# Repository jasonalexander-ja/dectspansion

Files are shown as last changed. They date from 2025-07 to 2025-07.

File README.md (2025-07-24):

# DECTspansion 

A DECT module for your EMFCamp Tildagon badge. 

Requires a headphone input. 

Based on [sc14cvmdect-devboard](https://github.com/funkeleinhorn/sc14cvmdect-devboard) by [funkeleinhorn](https://github.com/funkeleinhorn) and [EMFCamp](https://www.emfcamp.org/) [hexpansion](https://github.com/emfcamp/badge-2024-hardware/tree/main/hexpansion). 

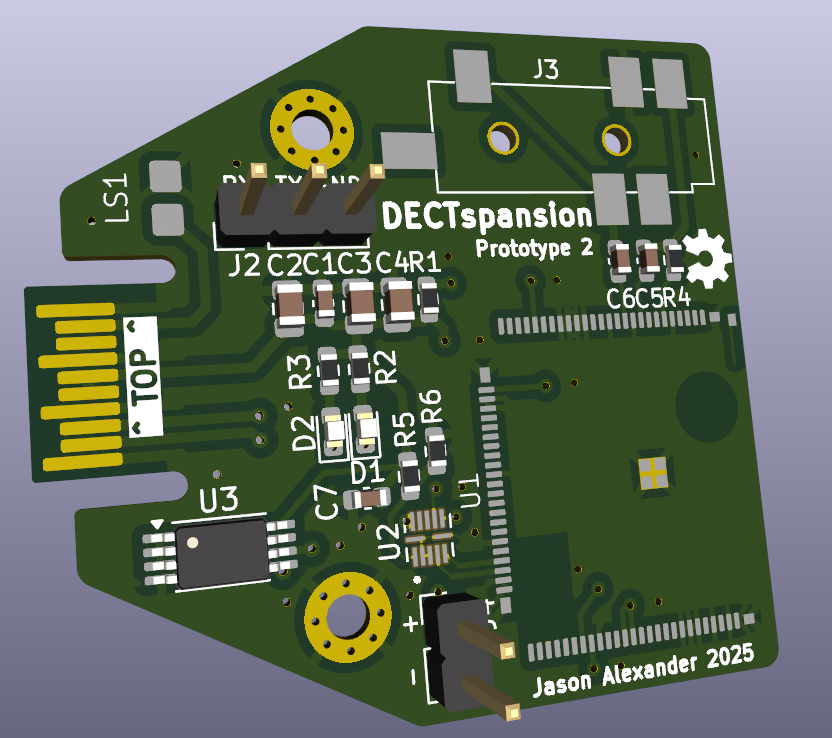
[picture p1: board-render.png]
Rendered image of the front of the PCB.


Currently in early prototype stage. 

## Components 

| Component | Value | Footprint |
|---|---|---|
| C1 | 47pF | 0603 |
| C2 | 2.2uF | 0805 |
| C3 | 10uF | 0805 |
| C4 | 2.2uF | 0805 |
| C5 | 100nF | 0603 |
| C6 | 1nF | 0603 |
| C7 | 47pF | 0603 |
| D1 | OSK40603C1E | 0603 |
| D2 | ORH-B36G | 0603 |
| J2 | 1x3 Pin header | 2.54mm |
| J3 | SJ-4351X | SMT audio jack |
| J4 | 1x2 Pin header | 2.54mm |
| R1 | 1K | 0603 |
| R2 | 470R | 0603 |
| R3 | 470R | 0603 |
| R4 | 1K | 0603 |
| R5 | 1K | 0603 |
| R6 | 1K | 0603 |
| U1 | SC14VCMDECT | |
| U2 | 74AVC4T3144 | XQFN12 |
| U3 | ZD24C64A | TSSOP-8 |
| LS1 | CMT-322-65 | |

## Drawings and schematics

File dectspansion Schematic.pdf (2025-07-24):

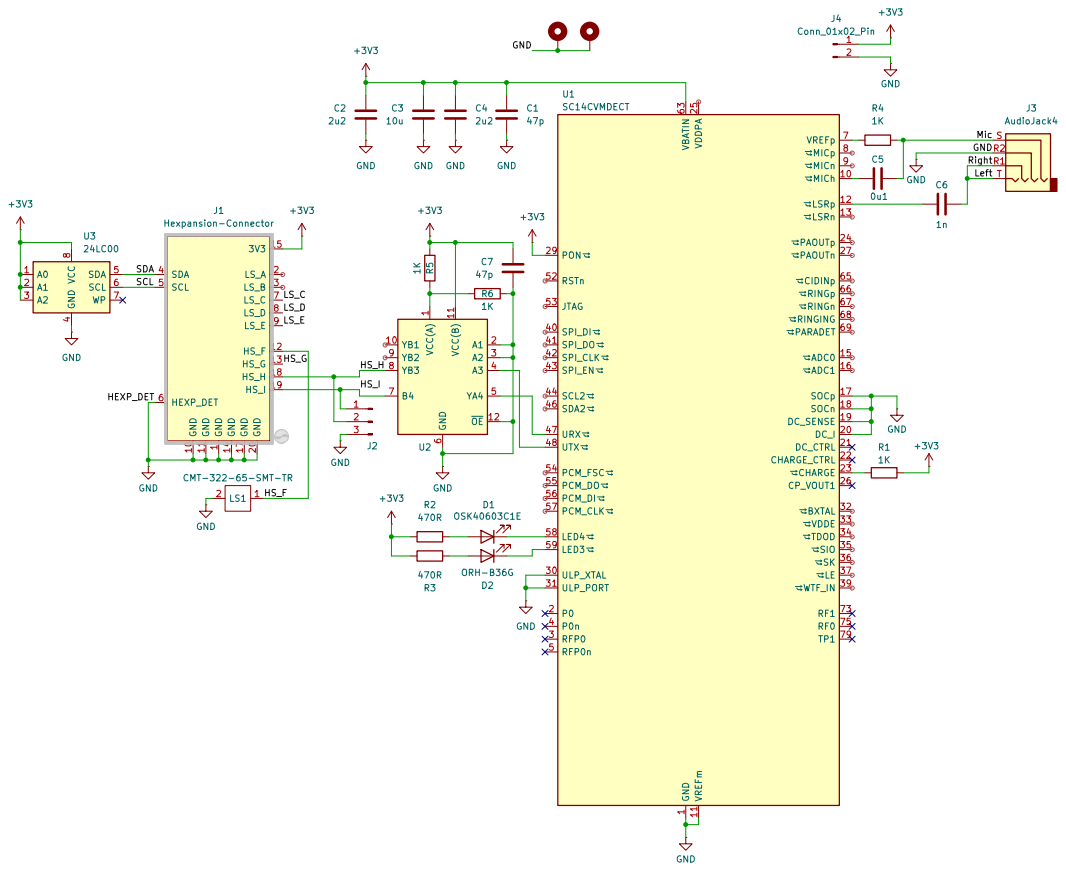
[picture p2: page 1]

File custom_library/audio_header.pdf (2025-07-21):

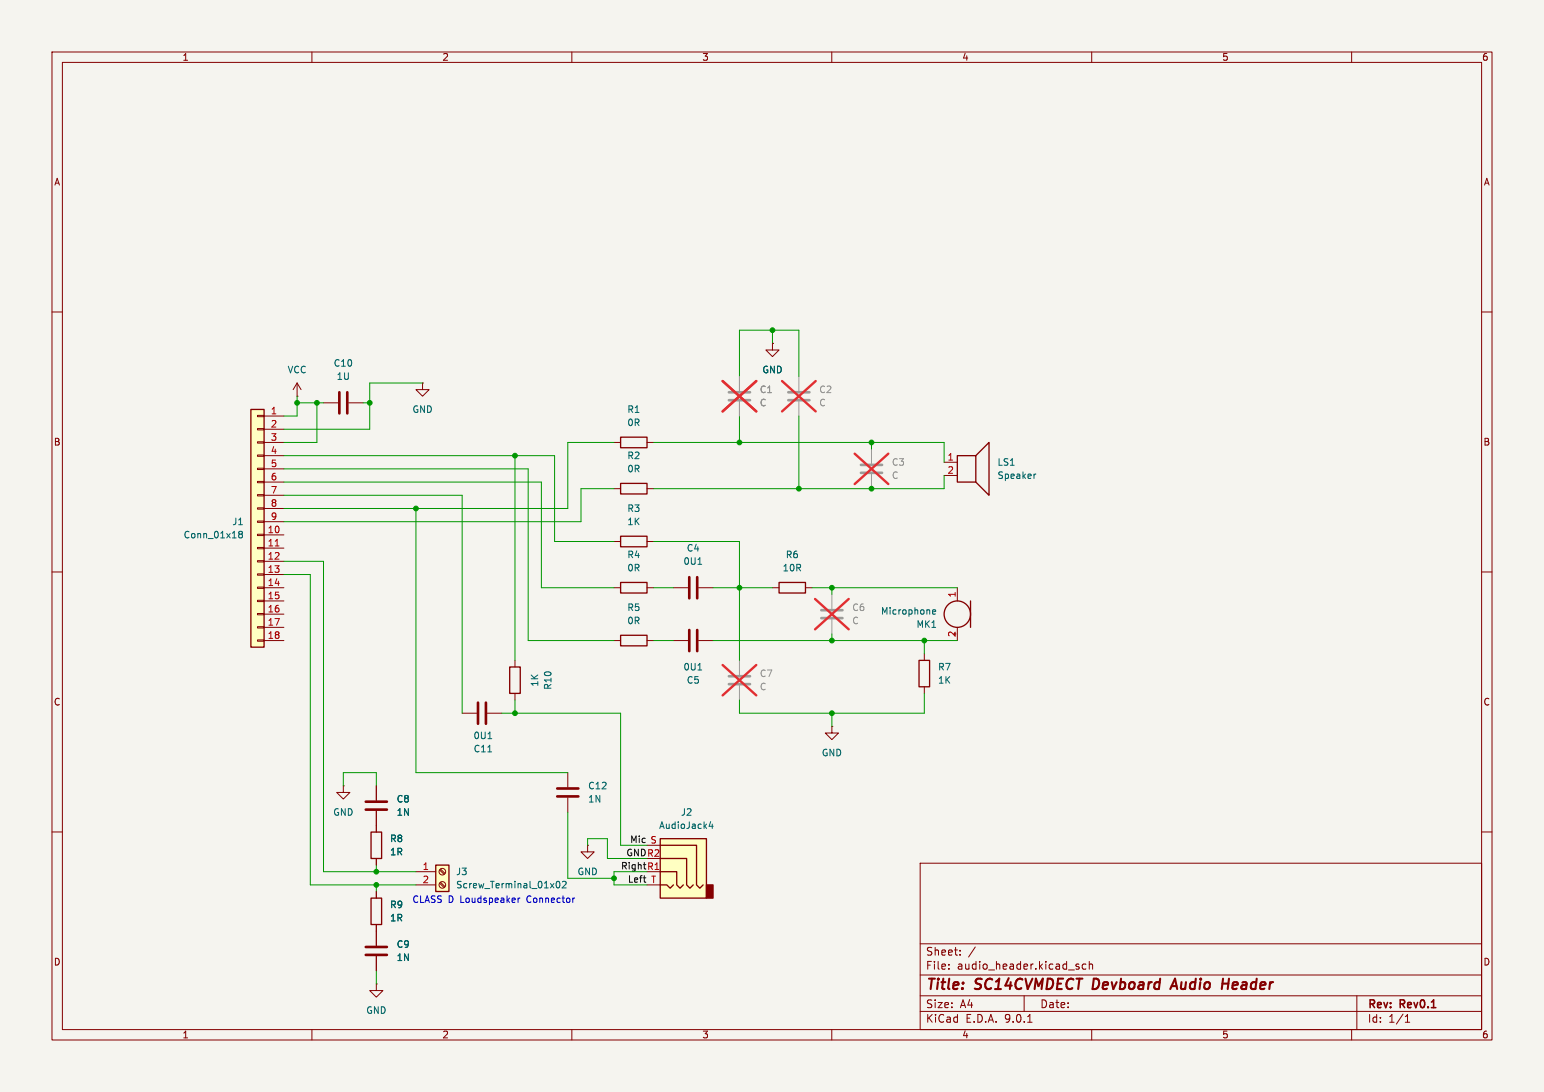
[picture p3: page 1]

10 11 12

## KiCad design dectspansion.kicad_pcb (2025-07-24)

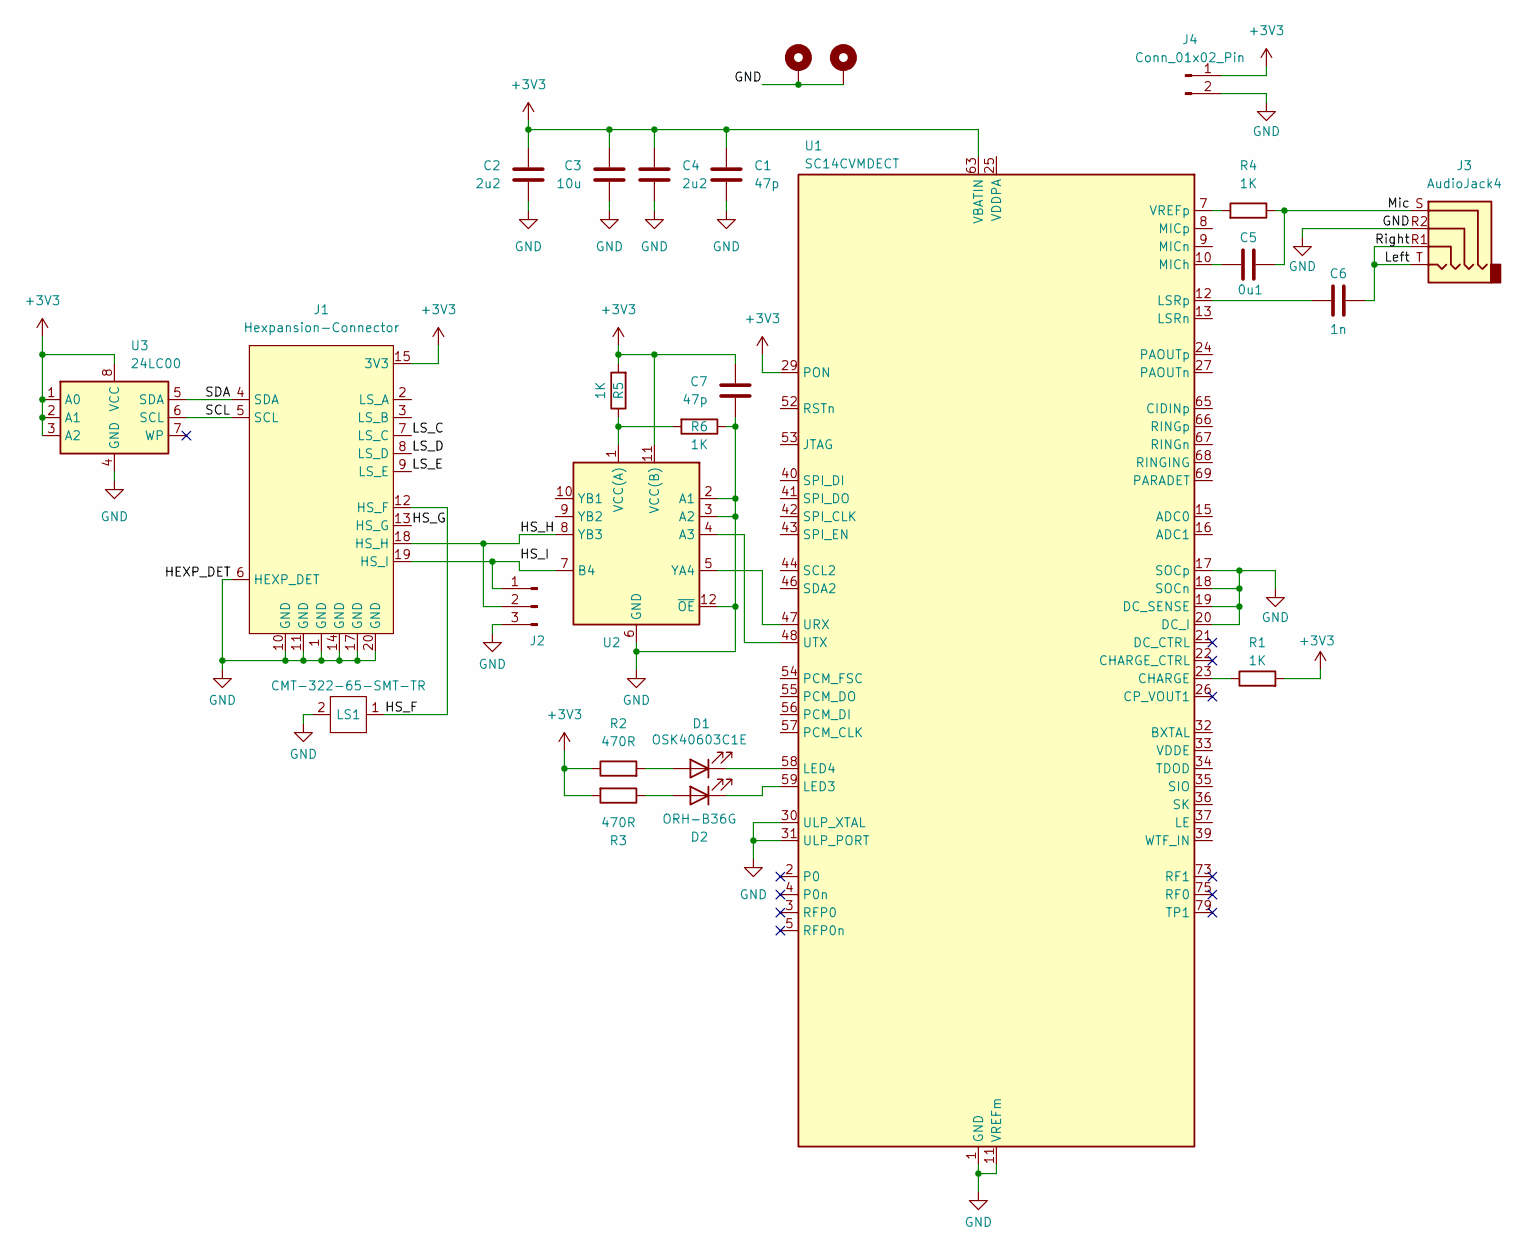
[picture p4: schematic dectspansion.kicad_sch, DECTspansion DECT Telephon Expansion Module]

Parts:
C1, C7: 47p; C_0603_1608Metric
C2, C4: 2u2; C_0805_2012Metric
C3: 10u; C_0805_2012Metric
C5: 0u1; C_0603_1608Metric
C6: 1n; C_0603_1608Metric
D1: OSK40603C1E; LED_0603_1608Metric
D2: ORH-B36G; LED_0603_1608Metric
H1, H2: MountingHole_Pad; MountingHole_2.2mm_M2_Pad_Via
J1: Hexpansion-Connector; hexpansion-edge-connector
J2: Conn_01x03_Pin; PinHeader_1x03_P2.54mm_Vertical
J3: AudioJack4; Jack_3.5mm_CUI_SJ-4351X-SMT_Horizontal
J4: Conn_01x02_Pin; PinHeader_1x02_P2.54mm_Vertical
LS1: CMT-322-65-SMT-TR
R1, R4, R5, R6: 1K; R_0603_1608Metric
R2, R3: 470R; R_0603_1608Metric
U1: SC14CVMDECT
U2: 74AVC4T3144
U3: 24LC00; TSSOP-8_4.4x3mm_P0.65mm

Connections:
+3V3: C1.1, C2.1, C3.1, C4.1, C7.1, J1.15 (3V3), J1.16 (3V3), J4.1, R1.2, R2.1, R3.2, R5.2, U1.29 (PON), U1.63 (VBATIN), U1.64 (VBATIN), U2.11 (VCC(B)), U3.1 (A0), U3.2 (A1), U3.3 (A2), U3.8 (VCC)
/HS_F: J1.12 (HS_F), LS1.1
/HS_G: J1.13 (HS_G)
/HS_H: J1.18 (HS_H), J2.2, U2.8 (YB3)
/HS_I: J1.19 (HS_I), J2.1, U2.7 (B4)
/LS_C: J1.7 (LS_C)
/LS_D: J1.8 (LS_D)
/LS_E: J1.9 (LS_E)
/Left: C6.1, J3.R1, J3.T
/Mic: C5.2, J3.S, R4.1
/SCL: J1.5 (SCL), U3.6 (SCL)
/SDA: J1.4 (SDA), U3.5 (SDA)
GND: C1.2, C2.2, C3.2, C4.2, C7.2, H1.1, H2.1, J1.1 (GND), J1.6 (HEXP_DET), J1.10 (GND), J1.11 (GND), J1.14 (GND), J1.17 (GND), J1.20 (GND), J2.3, J3.R2, J4.2, LS1.2, R6.1, U1.1 (GND), U1.6 (GND), U1.11 (VREFm), U1.14 (GND), U1.17 (SOCp), U1.18 (SOCn), U1.19 (DC_SENSE), U1.20 (DC_I), U1.28 (GND), U1.30 (ULP_XTAL), U1.31 (ULP_PORT), U1.38 (GND), U1.45 (GND), U1.49 (GND), U1.50 (GND), U1.51 (GND), U1.60 (GND), U1.70 (GND), U1.71 (GND), U1.72 (GND), U1.74 (GND), U1.76 (GND), U1.77 (GND), U1.78 (GND), U1.80 (GND), U2.2 (A1), U2.3 (A2), U2.6 (GND), U2.12 (~OE), U3.4 (GND)
unnamed: D1.2 (A), R2.2
unnamed: D1.1 (K), U1.58 (LED4)
unnamed: D2.2 (A), R3.1
unnamed: D2.1 (K), U1.59 (LED3)
unnamed: R1.1, U1.23 (CHARGE)
unnamed: C6.2, U1.12 (LSRp)
unnamed: C5.1, U1.10 (MICh)
unnamed: U1.47 (URX), U2.5 (YA4)
unnamed: U1.48 (UTX), U2.4 (A3)
unnamed: R4.2, U1.7 (VREFp)
unnamed: R5.1, R6.2, U2.1 (VCC(A))

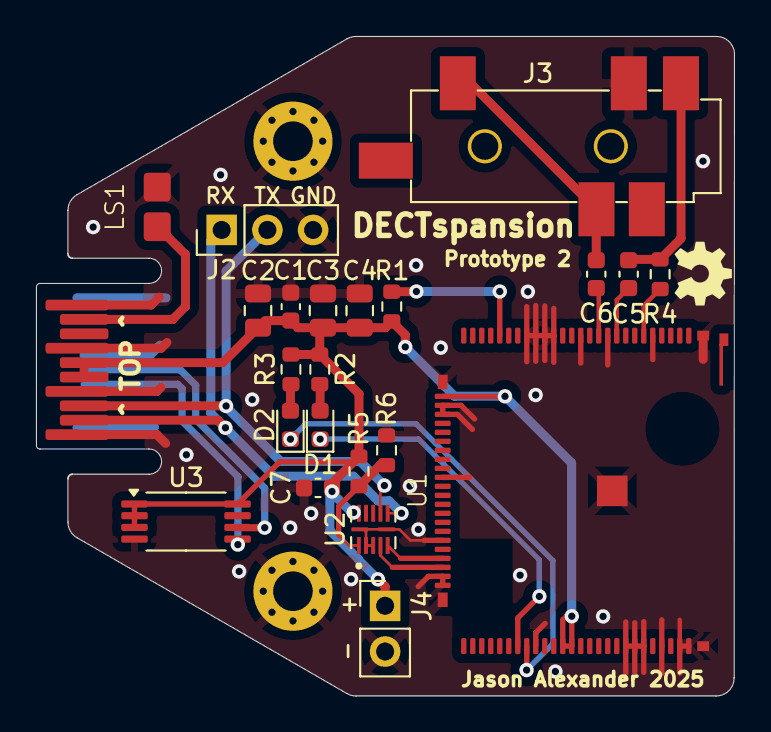
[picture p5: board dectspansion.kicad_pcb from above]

Board: 4 copper layers, 38.8 x 36.6 mm, 25 parts (0 on the bottom side), 20 nets.

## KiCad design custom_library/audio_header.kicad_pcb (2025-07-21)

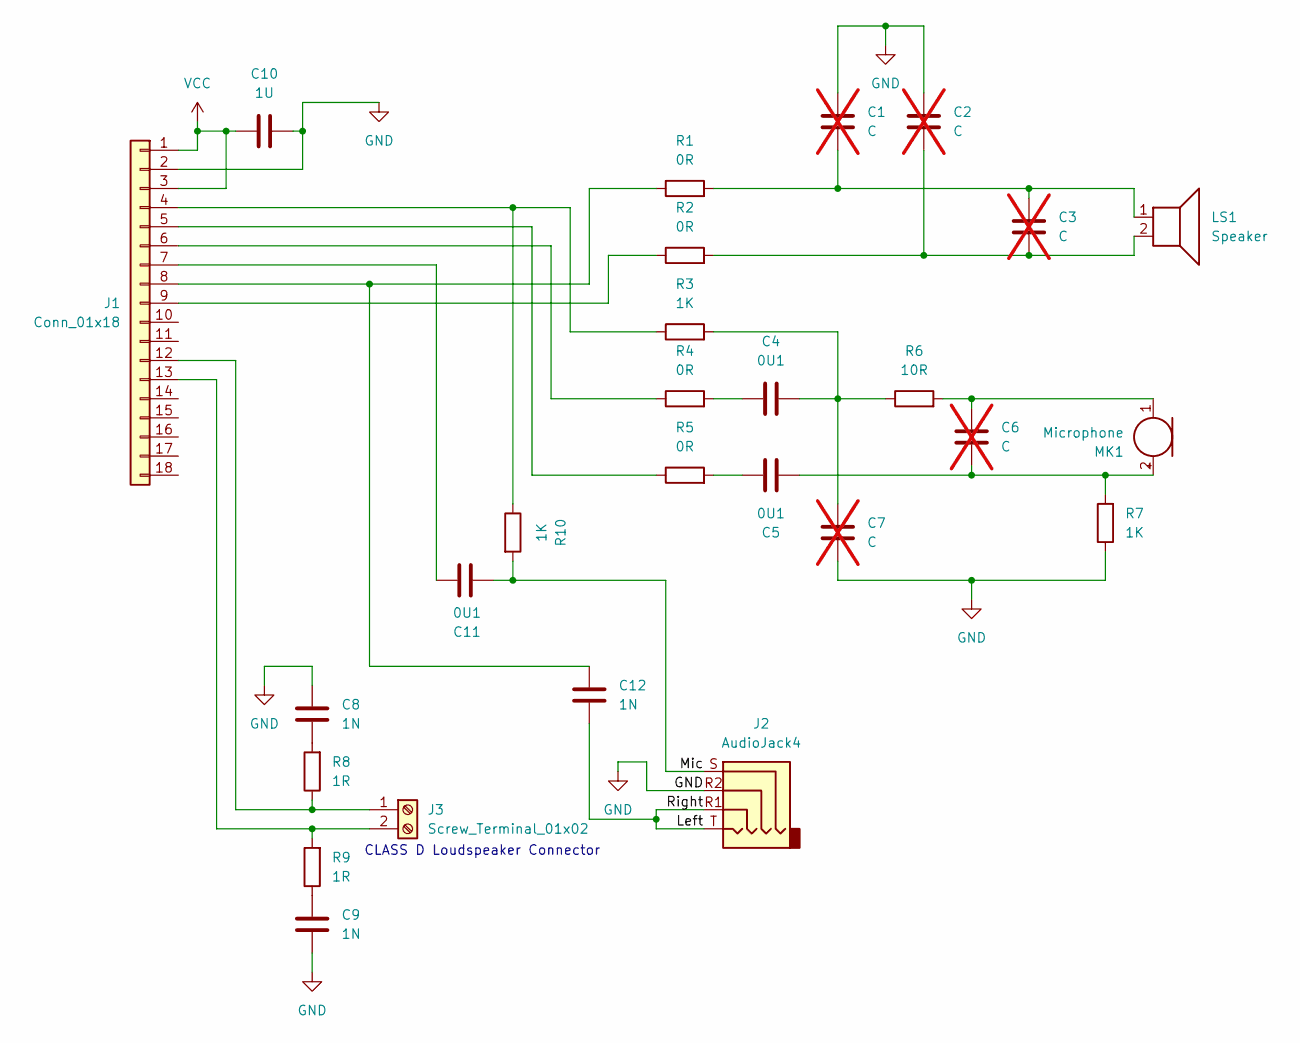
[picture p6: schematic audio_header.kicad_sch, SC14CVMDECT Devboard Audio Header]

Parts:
C1, C2, C3, C6, C7: C; C_0603_1608Metric; not fitted
C4, C5, C11: 0U1; C_0603_1608Metric
C8, C9, C12: 1N; C_0603_1608Metric
C10: 1U; C_0603_1608Metric
J1: Conn_01x18; PinSocket_1x18_P2.54mm_Vertical
J2: AudioJack4; Jack_3.5mm_CUI_SJ-4351X-SMT_Horizontal
J3: Screw_Terminal_01x02; TerminalBlock_MaiXu_MX126-5.0-02P_1x02_P5.00mm
LS1: Speaker; Speaker_CUI_CMR-15062S-67
MK1: Microphone; CUI_CMC-4013-SMT
R1, R2, R4, R5: 0R; R_0603_1608Metric
R3, R7, R10: 1K; R_0603_1608Metric
R6: 10R; R_0603_1608Metric
R8, R9: 1R; R_0603_1608Metric

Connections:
/Left: C12.1, J2.R1, J2.T
/Mic: C11.2, J2.S, R10.2
GND: C1.1, C2.1, C7.2, C8.2, C9.1, C10.2, J1.2, J2.R2, R7.1
unnamed: C1.2, C3.1, LS1.1, R1.2
unnamed: C2.2, C3.2, LS1.2, R2.2
unnamed: C4.1, R4.2
unnamed: C4.2, C7.1, R3.2, R6.1
unnamed: C5.1, R5.2
unnamed: C8.1, R8.2
unnamed: C9.2, R9.1
unnamed: J1.4, R3.1, R10.1
unnamed: J1.5, R5.1
unnamed: J1.6, R4.1
unnamed: C11.1, J1.7
unnamed: C12.2, J1.8, R1.1
unnamed: J1.9, R2.1
unnamed: J1.12, J3.1, R8.1
unnamed: J1.13, J3.2, R9.2
unnamed: C5.2, C6.2, MK1.2 (+), R7.2
unnamed: C6.1, MK1.1 (-), R6.2
VCC: C10.1, J1.1, J1.3

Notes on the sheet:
CLASS D Loudspeaker Connector

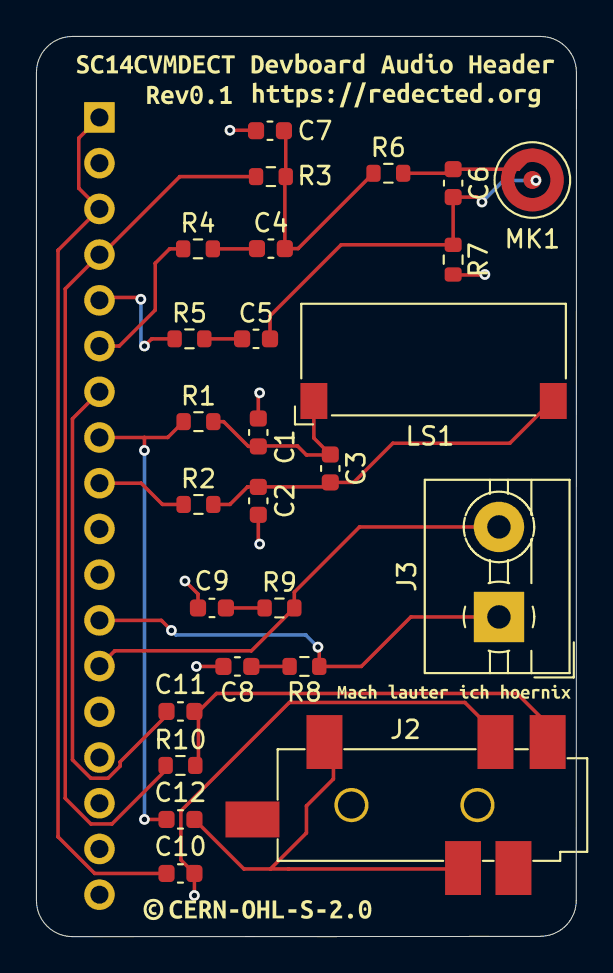
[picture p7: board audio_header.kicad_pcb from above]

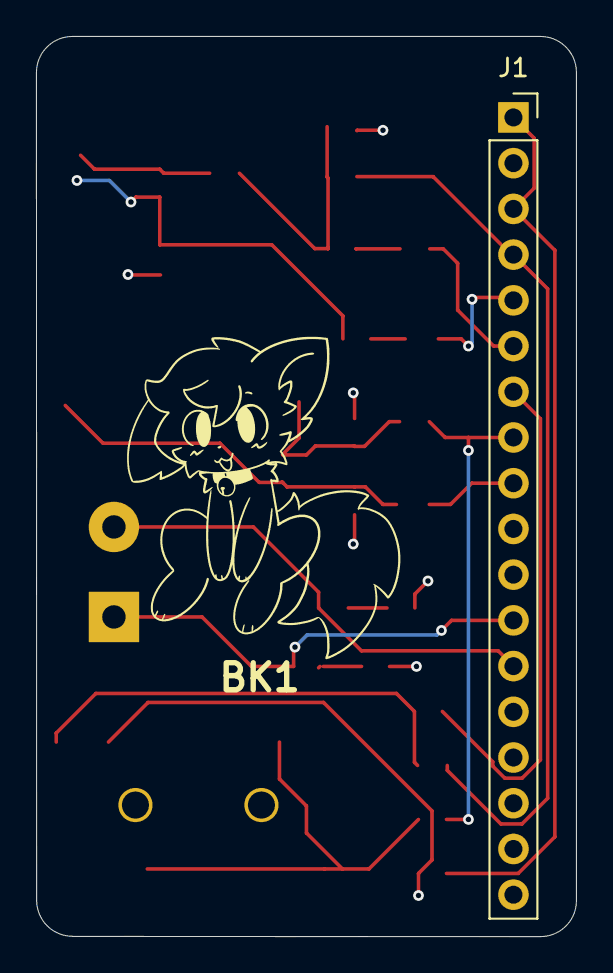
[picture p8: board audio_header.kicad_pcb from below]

Board: 4 copper layers, 30.0 x 50.0 mm, 34 parts (2 on the bottom side), 21 nets.

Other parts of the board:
BK1: LOGO
kibuzzard-67A72E30: G***; kibuzzard-67A72E30
kibuzzard-67A72F6B: G***; kibuzzard-67A72F6B
kibuzzard-67A72F64: G***; kibuzzard-67A72F64
kibuzzard-67A72F83: G***; kibuzzard-67A72F83
kibuzzard-67A7302E: G***; kibuzzard-67A7302E
kibuzzard-67ACE384: G***; kibuzzard-67ACE384

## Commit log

2025-07-21 Created PCB layout
    [dectspansion.kicad_pcb, dectspansion.kicad_sch]
2025-07-21 Adjustments to PCB layout
    [dectspansion.kicad_pcb]
2025-07-21 Added gerbers
    [dectspansion-B_Cu.gbl, dectspansion-B_Mask.gbs, dectspansion-B_Paste.gbp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]
2025-07-22 Adjustments to schmatic, board layout, and added part list to readme
    [dectspansion-B_Cu.gbl, dectspansion-B_Mask.gbs, dectspansion-B_Paste.gbp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]
2025-07-22 Added gerbers to zip
2025-07-22 Added uart level shifting
    [dectspansion-B_Cu.gbl, dectspansion-B_Mask.gbs, dectspansion-B_Paste.gbp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]
2025-07-22 Added level shifitng, updated schematic, layout and gerbers
    [dectspansion-B_Cu.gbl, dectspansion-B_Mask.gbs, dectspansion-B_Paste.gbp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]
2025-07-23 Fixed bug
    [dectspansion-B_Cu.gbl, dectspansion-B_Mask.gbs, dectspansion-B_Paste.gbp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]
2025-07-23 Added eeprom to board, updated to prototype 2
    [dectspansion-B_Cu.gbl, dectspansion-B_Mask.gbs, dectspansion-B_Paste.gbp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]
2025-07-23 Removed eeprom capacitors, and solder jumper
    [dectspansion-B_Cu.gbl, dectspansion-B_Mask.gbs, dectspansion-B_Paste.gbp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]
2025-07-24 Added piezo ringer
    [dectspansion-B_Cu.gbl, dectspansion-B_Mask.gbs, dectspansion-B_Paste.gbp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]
2025-07-24 Added PDF schematic
2025-08-09 Added HTML bom

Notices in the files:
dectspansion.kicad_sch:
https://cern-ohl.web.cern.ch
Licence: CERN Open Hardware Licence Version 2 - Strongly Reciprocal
